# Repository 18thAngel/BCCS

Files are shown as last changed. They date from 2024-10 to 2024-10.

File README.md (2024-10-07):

# BCCS - Brick compatible color shelf

- [BCCS - Brick compatible color shelf](#bccs---brick-compatible-color-shelf)
  - [What is this project about?](#what-is-this-project-about)
  - [How did this project come about?](#how-did-this-project-come-about)
  - [What about the angle bricks?](#what-about-the-angle-bricks)
  - [How to use](#how-to-use)
    - [Pre requirements / Used Software](#pre-requirements--used-software)
    - [Definitions](#definitions)
    - [General](#general)
      - [Customizer - General Settings - Section](#customizer---general-settings---section)
        - [Num Of Fragments](#num-of-fragments)
          - [Example for preview](#example-for-preview)
          - [Example for rendered version](#example-for-rendered-version)
        - [Even number of BrickUnits](#even-number-of-brickunits)
        - [Show Debug outputs and object](#show-debug-outputs-and-object)
    - [Color Holder](#color-holder)
      - [Customizer - Bottle Settings - Section](#customizer---bottle-settings---section)
        - [Clearance](#clearance)
        - [Bottle Type / UserDefined Bottle Diameter](#bottle-type--userdefined-bottle-diameter)
        - [Wall](#wall)
      - [Customizer - Column Settings - Section](#customizer---column-settings---section)
        - [Num of Columns](#num-of-columns)
        - [Space Between Columns](#space-between-columns)
    - [AngleBrick](#anglebrick)
      - [General](#general-1)
  - [Known Issues](#known-issues)
    - [Bricks are very tight](#bricks-are-very-tight)

## What is this project about?

This project allows the creation and printing of compatible holders for building blocks (like LEGO), making it easier to organize and store things like airbrush or tattoo colors. However, during the project, it actually split into two exciting sub-projects:

    The Bottle Holder
    The Angle Brick

## How did this project come about?

My wife, a passionate tattoo artist, asked if I could print her a tiered shelf for her tattoo colors. After discussing the idea, we identified three key requirements that most existing solutions didn’t quite meet:

    Scalability:S
    The collection of colors keeps growing. It would be great if the shelf could expand easily without having to print everything from scratch.

    Adjustable sizes & modularity:
    Different manufacturers have different bottle sizes. A flexible system that can handle various sizes would be ideal. Additionally, when you have more bottles of a particular size, it would be great to use the space more efficiently. This is where a modular system comes in handy.

    Quick to print:
    Let's be honest—many existing solutions take forever to print due to the time needed for the shelf or the underlying structure. But why not use something we already have lying around in abundance, or can get cheaply from third-party suppliers? In this solution, only the actual holders are printed, while the rest is built with building blocks.

## What about the angle bricks?

We’ve all been there: after printing the first few parts, you think, “Hey, this would be even cooler if...”. In this case, the idea was to have angled shelves. Instead of printing new shelves with slanted bases (which I actually tested once), I thought, why not use the formulas I already had for the base calculations to print a brick that serves as an adapter? And voilà, the angle brick was born!

## How to use
### Pre requirements / Used Software
If you want to create a holder based on your own requirements, you'll need the software:
- OpenSCAD (https://openscad.org)

### Definitions
| Term | Explanation |
|---|---|
|`[BrickUnit]`| Size of a single step that can be used for the <br/> `[Width]` or `[Depth]` of a brick. |
| `[BrickLayer]`, `[Layer]`| Size of a single step that can be used for the <br/> `[Height]` dimension of a brick.<br/> (3-layers equal a "normal" brick height )|

### General
All changes should be made within the `Customizer` from OpenSCAD.
Both projects have a `General Settings - Section` with the following parameters.
Whenever something is related to size units. Those are in millimeter [mm] if nothing else is mentioned.

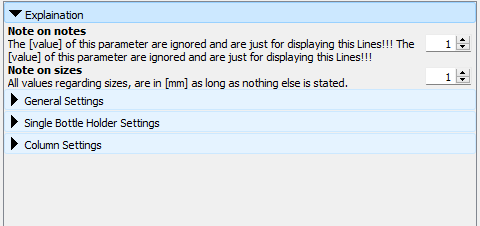
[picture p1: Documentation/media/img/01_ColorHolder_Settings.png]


#### Customizer - General Settings - Section
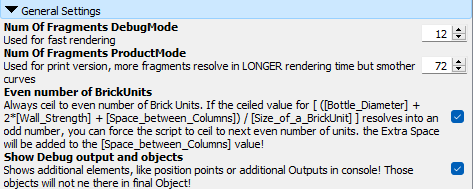
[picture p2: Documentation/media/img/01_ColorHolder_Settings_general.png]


##### Num Of Fragments
As Preview rendering is done in no time at all, it is not that accurate. Therefor any Round surface will be rendered with a limited amount of Fragments. Increasing one of that parameters, will lead to a smoother surface.

###### Example for preview
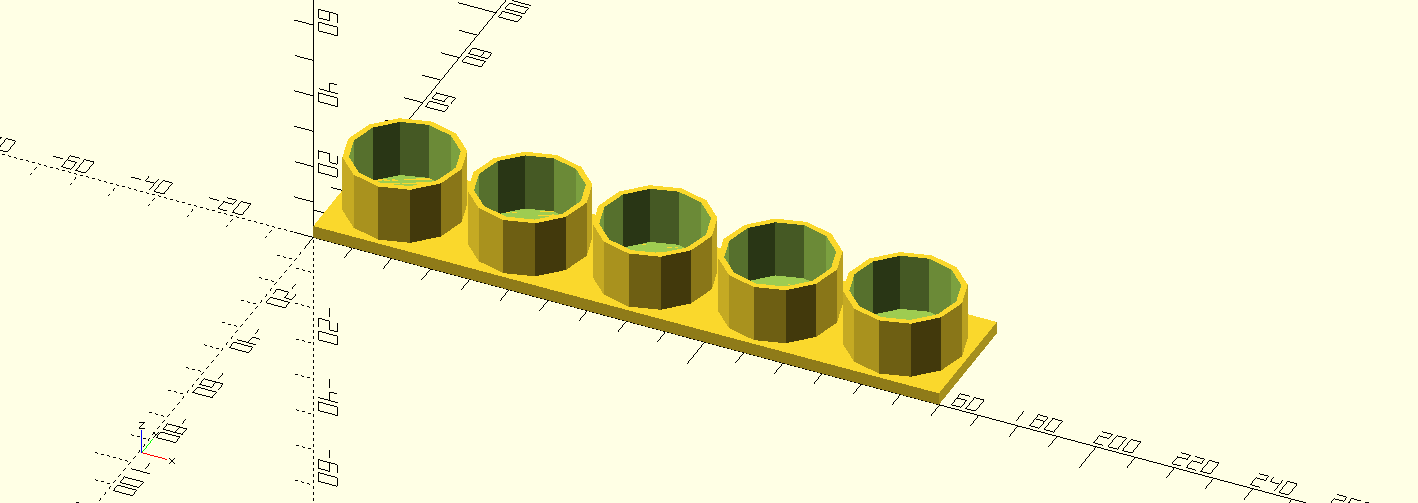
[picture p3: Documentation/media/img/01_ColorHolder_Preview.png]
Example for preview


###### Example for rendered version
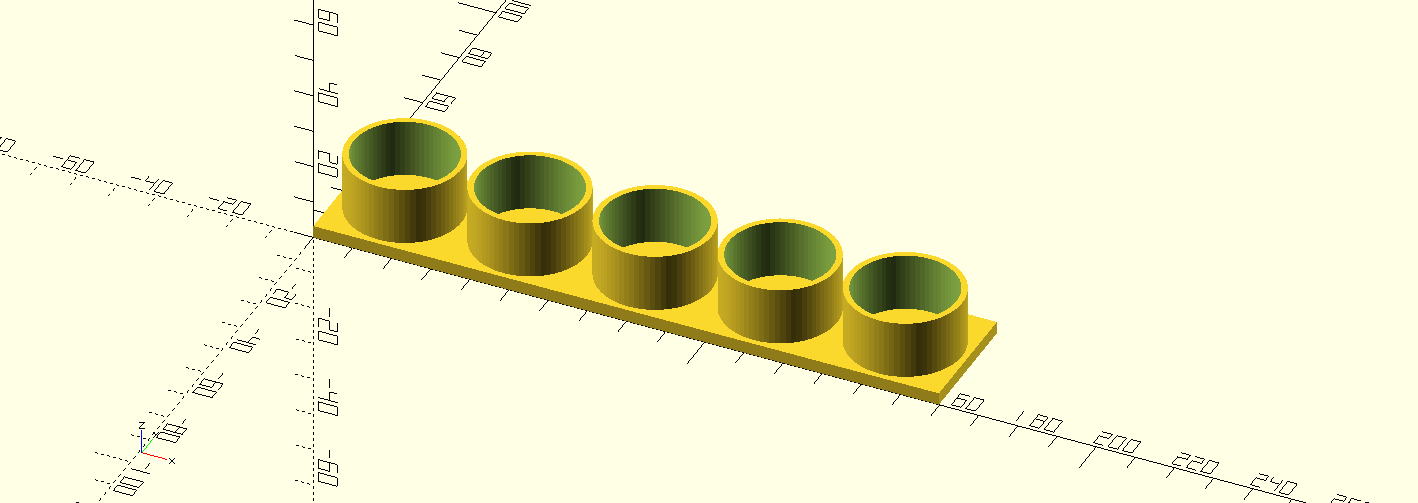
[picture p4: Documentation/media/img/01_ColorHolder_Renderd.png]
Example for rendered version


##### Even number of BrickUnits
To ensure the compatibility to the leading brick systems, the script will always ceil towards whole `[brickUnits]`.

If this option is ticked, it will not just ceil to the next whole `[brickUnit]`, but also to the next __EVEN__ `[brickUnit]`. This can for example be useful to match sizes of baseplates.

##### Show Debug outputs and object
If this option is ticked, additional information are echoed towards console or additional objects might appear on preview. This will be removed while rendering for stl - Export.

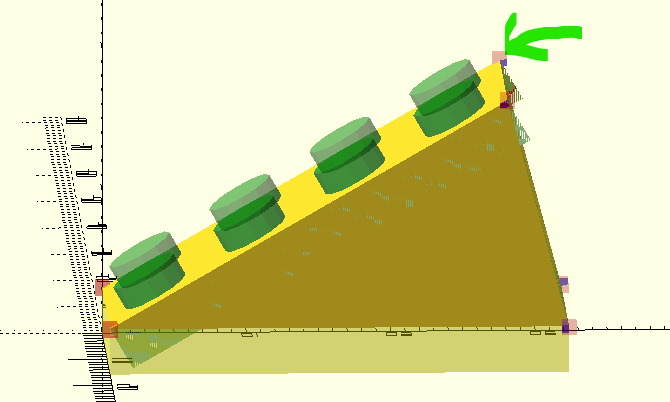
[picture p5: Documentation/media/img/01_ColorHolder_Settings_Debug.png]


### Color Holder
#### Customizer - Bottle Settings - Section
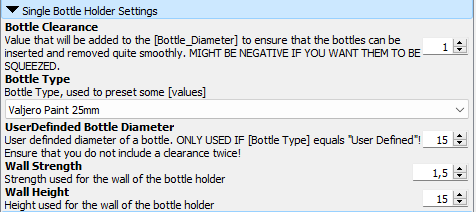
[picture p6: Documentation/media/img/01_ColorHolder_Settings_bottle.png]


##### Clearance
The `[value]` of this parameter will be added to `[bottle diameter]`. To ensure that bottles can be slide in and out easily. 

##### Bottle Type / UserDefined Bottle Diameter
A set of predefined `[bottle diameters]` that are needed frequently.
If the value `User Defined` is selected, the `[UserDefined_Bottle_Diameter]` - value will be used.

##### Wall
The parameters `[Strength]` and `[Height]` define exactly what they are named. 
How thick / high the Wall of the bottleHolder will be.

#### Customizer - Column Settings - Section


##### Num of Columns
Exactly what it sounds like

##### Space Between Columns
This value is more or less the `[min space between holders]`.
After calculating the needed `[brickUnits]` for the holder, the script will spread the holders even over the available space. But sometimes it can save one or two `[brickUnits]` if holder walls, that would normally be touching, would be merged. this can be done by setting this value to a negative value.

__NOTE / TO DO:__ this value must not be set to a value lower than `-[WallStrength]`!<br/>
It is planed to implement a check on that in future versions!

### AngleBrick
#### General
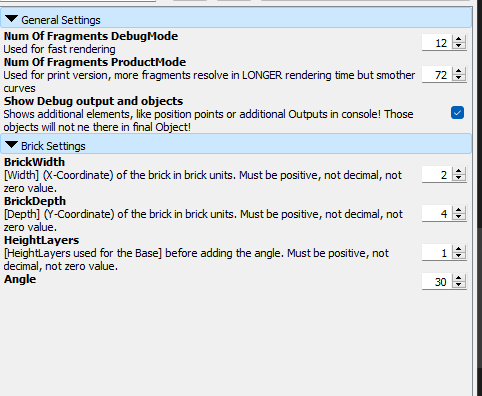
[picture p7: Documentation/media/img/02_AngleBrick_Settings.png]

 Settings for the AngleBrick are straight forward and do not need many explanation.

__Only important info__ is, that the `[Angle]` - value may not be lower than 0°or higher than 90°

## Known Issues
### Bricks are very tight
Reason for that is that i used real dimensions but only have a 0.4 Nozzle. Most likely i will add a little more clearance.
After placing it on a brick with a reasonable amount of force on a "`non printed one`" it will snap in on others as expected

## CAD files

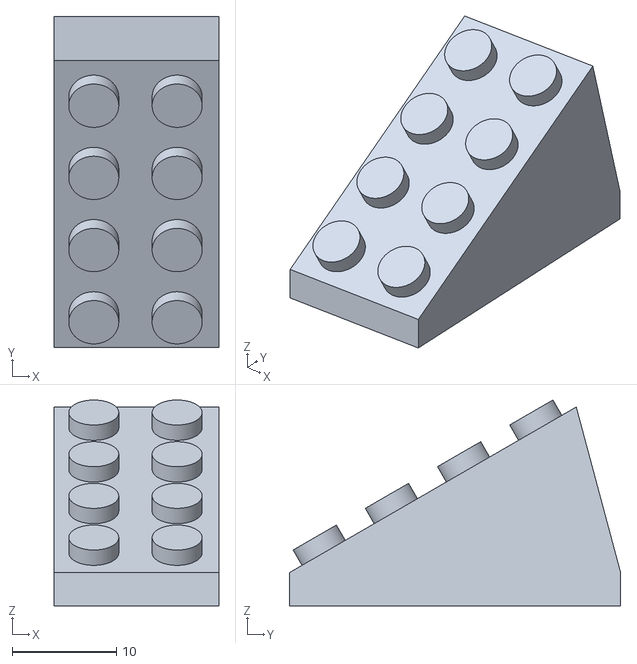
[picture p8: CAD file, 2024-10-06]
Precreated_stls/AngleBrick-2x4_Units-30_Degrees-1_Layer.stl
15.8 x 31.8 x 19.8

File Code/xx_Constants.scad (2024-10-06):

///////////////////////////////////////////////////////////////
// Part of the "Brick compatible color shelf" (BCCS) project //
// File: xx_Constants.scad                                   //
//                                                           //
// By: Alexander Szymanski / 18thAngel                       //
///////////////////////////////////////////////////////////////

// This file generates all important values that are needed to be compatible with most
// modual brick systems.
// The core values have been take from Wikipedia article as of 2024-10-05:
// - https://en.wikipedia.org/wiki/Lego#Design
// - https://en.wikipedia.org/wiki/Lego#/media/File:Lego_dimensions.svg
// some might have been slightly modified to match printers offset


/*[Hidden]*/
///////////////////////
///////////////////////
//// Brick Related ////
///////////////////////
///////////////////////

// as found in Wiki
SmallHeight_of_a_Brick = 3.2; 

// as found in Wiki
Height_of_a_BrickHead = 1.7;

// as found in Wiki
Diameter_of_a_BrickHead = 4.8;

// as found in Wiki
Clearance_of_a_Brick = 0.2;

// messured from a brick on my desk
InnerWallStrength_of_a_Brick = 0.85;

// assumed
TopWallStrength_of_a_Brick = 1.2;

//TODO: make it a param in customizer!
// This is just, as my printer is not that precise
OutterWallStrength_additional_clearance= 0.1;

//////////////////////////
// Precalculated Values //
//////////////////////////

// A brick can be cutted in three parts / layers 
// and is allowed to be any non decimal multiplication of that layer height
// Original the normal brick is SmallHeight_of_a_Brick * 3;
Height_of_a_Brick = SmallHeight_of_a_Brick * 3;

// Values, that are related to width and depth of a brick are fixed to brick units
// 1 brick unit is calculated by SmallHeight_of_a_Brick * 2.5;
// Values [Width] and [Depth] of a brick must match a non decimal multiplication of a brick unit
Size_of_a_BrickUnit = SmallHeight_of_a_Brick * 2.5;

// Value that is used for any outter walls regarding [Width] and [Depth], most likely it could also be used for height
// Calculation:
// ([Size of a single brick unit] - [clearance of a brick] - [diameter of a brick head]) / 2
OutterWallStrength_of_a_Brick = ((Size_of_a_BrickUnit - Clearance_of_a_Brick - Diameter_of_a_BrickHead) / 2)-OutterWallStrength_additional_clearance;

// For better fitting, the total [Width] and [Depth] of a brick will be lowered by 0.2 mm
// that helps to stack those bricks, or tear them apart
Width_of_a_Brick = Size_of_a_BrickUnit - Clearance_of_a_Brick;

// Simple Diameter => Radius calc
Radius_of_a_BrickHead = Diameter_of_a_BrickHead / 2;

// According to the Specs, it should be +0.1,
// as it doubles up when we convert it back to a radius
// but in this case it did not worked with my printer! 
// this value will be substracted (difference) from [OutterRadius_of_a_BrickHole]
InnerRadius_of_a_BrickHole = Radius_of_a_BrickHead + 0.2;

// Size of a brickhead increased the strength of inner walls
OutterRadius_of_a_BrickHole = Radius_of_a_BrickHead + InnerWallStrength_of_a_Brick;

// Thickness used for the [Thickness:Z] of the tile base. For Historical Reasons!
Thickness_of_tile_base = SmallHeight_of_a_Brick;

////////////////////////
////////////////////////
//// Bottle Related ////
////////////////////////
////////////////////////

////////////////////
// Bottle_presets //
////////////////////
_v_diameter = 25;
_gb26_diameter = 26;
_gb30_diameter = 30;
_gb32_diameter = 32;
_gb35_diameter = 35;
_gb37_diameter = 37;


// Not a const, i know! 
// returns the Diameter for the given string
function GetBottleDiameter(bottleType,userDefindedBottleDiameter) = 
  bottleType=="v" ? _v_diameter
: bottleType=="gb26" ? _gb26_diameter
: bottleType=="gb30" ? _gb30_diameter
: bottleType=="gb32" ? _gb32_diameter
: bottleType=="gb35" ? _gb35_diameter
: bottleType=="gb37" ? _gb37_diameter
:userDefindedBottleDiameter;

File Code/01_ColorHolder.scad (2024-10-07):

///////////////////////////////////////////////////////////////
// Part of the "Brick compatible color shelf" (BCCS) project //
// File: 01_ColorHolder.scad                                 //
//                                                           //
// By: Alexander Szymanski / 18thAngel                       //
///////////////////////////////////////////////////////////////

include <xx_Constants.scad>
include <xx_SharedStuff.scad>

/*[Explaination]*/
// The [value] of this parameter are ignored and are just for displaying this Lines!!! The [value] of this parameter are ignored and are just for displaying this Lines!!!
Note_on_notes = 1;
// All values regarding sizes, are in [mm] as long as nothing else is stated.
Note_on_sizes = 1;

/*[General Settings]*/
// Used for fast rendering
Num_Of_Fragments_DebugMode = 12;

// Used for print version, more fragments resolve in LONGER rendering time but smother curves
Num_Of_Fragments_ProductMode = 72;

// Always ceil to even number of Brick Units. If the ceiled value for [ ([Bottle_Diameter] + 2*[Wall_Strength] + [Space_between_Columns]) / [Size_of_a_BrickUnit] ] resolves into an odd number, you can force the script to ceil to next even number of units. the Extra Space will be added to the [Space_between_Columns] value!
Even_number_of_BrickUnits = true;

// Shows additional elements, like position points or additional Outputs in console! Those objects will not ne there in final Object!
Show_Debug_output_and_objects = true;

/*[Single Bottle Holder Settings]*/
// Value that will be added to the [Bottle_Diameter] to ensure that the bottles can be inserted and removed quite smoothly. MIGHT BE NEGATIVE IF YOU WANT THEM TO BE SQUEEZED.
Bottle_Clearance = 1;

// Bottle Type, used to preset some [values]
Bottle_Type =  "v"; // [ud:User Defined, v:Valjero Paint(25mm), gb26:Generic 26mm Bottle, gb30:Generic 30mm Bottle, gb32:Generic 32mm Bottle, gb35:Generic 35mm Bottle, gb37:Generic 37mm Bottle]

// User definded diameter of a bottle. ONLY USED IF [Bottle Type] equals "User Defined"! Ensure that you do not include a clearance twice!
UserDefinded_Bottle_Diameter = 15;

// determied by previous selections - not visible in Customizer!
Bottle_Diameter = GetBottleDiameter(Bottle_Type, UserDefinded_Bottle_Diameter) + Bottle_Clearance;

// Strength used for the wall of the bottle holder
Wall_Strength = 1.5;

// Height used for the wall of the bottle holder
Wall_Height = 15;

/*[Column Settings]*/
// Number of [bottles] per [row]
Num_of_Columns = 5;
// Space between [bottles] in a [row]. May be negative but only by [real space between bottle holders] + 1 * [Wall Strength]
Space_between_Columns = 1;


//////////////////////////////
// !!! No changes below !!! //
//////////////////////////////
include <xx_lateCalculatedValues.scad>
///////////////////////
// Value Calculation //
///////////////////////

// General
$fn = $preview ? Num_Of_Fragments_DebugMode : Num_Of_Fragments_ProductMode;

// Tile Related
// Size that is used for [Length:X] and [Depth:Y] of the tile
Size_of_Tile = Bottle_Diameter + 2 * Wall_Strength;

minSpaceBetweenColumns = (Bottle_Diameter + Wall_Strength) - Size_of_Tile;

tileDepth =
    CalcRealSize(Size_of_Tile, Size_of_a_BrickUnit, Even_number_of_BrickUnits);
tileDepthOverhead = tileDepth - Size_of_Tile;

///////////////////////
// Value Calculation //
///////////////////////

// Bottle related
BottleHolder_OutterRadius = Bottle_Diameter / 2 + Wall_Strength;
BottleHolder_InnerRadius = Bottle_Diameter / 2;

// Tile Related
BaseSizeWidth_tmp = (BottleHolder_OutterRadius * 2 * Num_of_Columns) +
                    ((Num_of_Columns)*Space_between_Columns);

BaseSizeWidth = CalcRealSize(BaseSizeWidth_tmp, Size_of_a_BrickUnit,
                             Even_number_of_BrickUnits);

BaseSizeWidth_overhead = BaseSizeWidth - BaseSizeWidth_tmp;

CalcedSpaceBetween =
    Space_between_Columns + (BaseSizeWidth_overhead / NotZero(Num_of_Columns));

///////////////////////////
unitsWidth = (BaseSizeWidth + Clearance_of_a_Brick) / Size_of_a_BrickUnit;
unitsDepth = (tileDepth+Clearance_of_a_Brick) / Size_of_a_BrickUnit;
///////////////////////////

if (DebugMode) {
  echo("");
  echo("----------------------------");
  echo("Important calculation results:");
  echo("");

  echo(str("The real base width for ", BaseSizeWidth_tmp,
           "mm has been calced to: ", BaseSizeWidth, "mm"));
  echo(str("CalcedSpaceBetween has been calced to ", CalcedSpaceBetween, "mm"));
  echo("");
  echo("----------------------------");
  echo("");

  echo("");
  echo("----------------------------");
  echo("Settings for a bottle:");
  echo("");
  echo(str("[Bottle Diameter] for [Bottle_Type]: ", Bottle_Type,
           " have been set to: ", Bottle_Diameter,
           "mm, including: ", Bottle_Clearance,
           "mm [Bottle Clearance], based on user preferences"));
  echo("");
  echo("----------------------------");
  echo("");

  echo("");
  echo("----------------------------");
  echo("Messures of a brick:");
  echo("");

  echo(str("Small height of a brick: ", SmallHeight_of_a_Brick, "mm (given)"));
  echo(str("Height of a brick head: ", Height_of_a_BrickHead, "mm (given)"));
  echo(
      str("Diameter of a brick head: ", Diameter_of_a_BrickHead, "mm (given)"));
  echo(str("Height of a brick: ", Height_of_a_Brick, "mm (calc)"));
  echo(str("Size of a brick unit: ", Size_of_a_BrickUnit, "mm (calc)"));
  echo(str("Width of a brick:  ", Width_of_a_Brick, "mm (calc)"));
  echo(str("Radius_of_a_BrickHead:  ", Radius_of_a_BrickHead, "mm (calc)"));
  echo(str("InnerRadius of a BrickHole:  ", InnerRadius_of_a_BrickHole,
           "mm (calc)"));
  echo(str("OutterRadius of a BrickHole:  ", OutterRadius_of_a_BrickHole,
           "mm (calc)"));
  echo("");

  echo("Messures the Holder:");
  echo("");
  echo(str("The real tile depth for ", Size_of_Tile,
           "mm has been calced to: ", tileDepth, "mm"));
  echo(str("The real base width for ", BaseSizeWidth_tmp,
           "mm has been calced to: ", BaseSizeWidth, "mm"));
  echo(str("Tile depth:  ", tileDepth, "mm (calc)"));
  echo(str("Tile width:  ", BaseSizeWidth, "mm (calc)"));
  echo(str("Tile depth:  ", unitsDepth, "units (calc)"));
  echo(str("Tile width:  ", unitsWidth, "units (calc)"));
  echo("");
  echo("----------------------------");
  echo("");

  echo(str("The real tile depth for ", Size_of_Tile,
           "mm has been calced to: ", tileDepth, "mm"));
}
// generates a single Holder
module BottleHolder() {
  translate([ 0, BottleHolder_OutterRadius + tileDepthOverhead / 2, 0 ]) {
    difference() {
      cylinder(Wall_Height, BottleHolder_OutterRadius,
               BottleHolder_OutterRadius);
      cylinder(Wall_Height + 0.1, BottleHolder_InnerRadius,
               BottleHolder_InnerRadius);
    }
  }
}
// generates a single Holder
module BottleHolders() {
  for (holder = [0:Num_of_Columns - 1]) {
    translate([
      (holder * (BottleHolder_OutterRadius * 2 + CalcedSpaceBetween)) +
          BottleHolder_OutterRadius,
      0,
      Thickness_of_tile_base
    ]) BottleHolder();
  }
}

// Generates a Single Row, in original version there were a multiple rows option!
module SolidHolder() {
  Base(unitsWidth,unitsDepth);
  translate([ CalcedSpaceBetween / 2, 0, 0 ]) BottleHolders();
}



/////////////////

/////////////
// Program //
/////////////

// in original version there were a multiple rows option!
SolidHolder();  

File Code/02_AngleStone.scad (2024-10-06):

///////////////////////////////////////////////////////////////
// Part of the "Brick compatible color shelf" (BCCS) project //
// File: 02_AngleStone.scad                                  //
//                                                           //
// By: Alexander Szymanski / 18thAngel                       //
///////////////////////////////////////////////////////////////

include <xx_Constants.scad>
include <xx_SharedStuff.scad>

/*[General Settings]*/
// Used for fast rendering
Num_Of_Fragments_DebugMode = 12;

// Used for print version, more fragments resolve in LONGER rendering time but smother curves
Num_Of_Fragments_ProductMode = 72;

// Shows additional elements, like position points or additional Outputs in console! Those objects will not ne there in final Object!
Show_Debug_output_and_objects = true;
/*[Brick Settings]*/
// [Width] (X-Coordinate) of the brick in brick units. Must be positive, not decimal, not zero value.
BrickWidth = 2;
// [Depth] (Y-Coordinate) of the brick in brick units. Must be positive, not decimal, not zero value.
BrickDepth = 4;
// [HeightLayers used for the Base] before adding the angle. Must be positive, not decimal, not zero value.
HeightLayers = 1;

Angle = 30;

//////////////////////////////
// !!! No changes below !!! //
//////////////////////////////
include <xx_lateCalculatedValues.scad>
///////////////////////
// Value Calculation //
///////////////////////

// General
$fn = $preview ? Num_Of_Fragments_DebugMode : Num_Of_Fragments_ProductMode;


_origin_x = GetSizeByBrickUnits(BrickWidth, Size_of_a_BrickUnit);
_origin_y = GetSizeByBrickUnits(BrickDepth, Size_of_a_BrickUnit);
_origin_z = SmallHeight_of_a_Brick * HeightLayers;


correctedPosition = CalcTanslationAfterRotation([0,0,_origin_z], Angle);
topLocation = CalcPositionAfterRotation([0,_origin_y,_origin_z], Angle) + correctedPosition ;
bottomLocation = CalcPositionAfterRotation([0,0,0], Angle) + correctedPosition;

// filling the gap
module GapFill() {

    _fillPoints=[
     [  0,  0, _origin_z ],  //0 
     [  _origin_x,  0, _origin_z ],  //1 
     [  _origin_x,  _origin_y, _origin_z ],  //2 
     [  0,  _origin_y, _origin_z ],  //3
     [  0,  topLocation[1], topLocation[2] ],  //4 
     [  _origin_x,  topLocation[1], topLocation[2] ],  //5 
     ];

    _fillFaces= [
        [0,1,2,3], // bottom
        [4,5,1,0], //Front
        [5,4,3,2],  // back
        [0,3,4],  // Left
        [1,2,5],  // right
    ];
hull() {
   polyhedron( _fillPoints, _fillFaces );
}
    if(DebugMode)
        for(point = _fillPoints)
            color("red",0.3) 
              translate(point)     
                cube(size = 1, center=true);
}

module buildTopPart()
{
    difference() 
    {
        translate(correctedPosition)
            rotate([Angle,0,0])
                color("green",0.5) 
                    Base(BrickWidth,BrickDepth, HeightLayers,true,false);
    
        //TODO; lazy way of cutting may be fixed 
        
        translate(correctedPosition+[0,0.1,-0.1])
            rotate([Angle,0,0])
                color("red",0.5) 
                    Base(BrickWidth,BrickDepth, HeightLayers,false,false);
        translate(correctedPosition+[0,-0.1,-0.1])
            rotate([Angle,0,0])
                color("red",0.5) 
                    Base(BrickWidth,BrickDepth, HeightLayers,false,false);
    }       
}

module buildTheBasic()
{
    buildTopPart();
    color("yellow",0.5) 
    Base(BrickWidth,BrickDepth, HeightLayers,false);
    
 
}

module Brick() {
  buildTheBasic();
  GapFill();
        
}

module FinalBrick() {
  difference() {
    Brick();
  BuildTheCutter();
  
    
    }
}

module BuildTheCutter() {
    _cutterPoints=[         
        [  0,  _origin_y, _origin_z ],  //1
        [  _origin_x,  _origin_y, _origin_z ],  //0 
        [  _origin_x,  _origin_y, _origin_z ]+ correctedPosition,  //3
        [  0,  _origin_y, _origin_z ] + correctedPosition,  //2
        [  0,  topLocation[1], topLocation[2] ],  //4 
        [  _origin_x,  topLocation[1], topLocation[2] ],  //5 
        [  _origin_x,  topLocation[1], topLocation[2] ]+ correctedPosition,  //6
        [  0,  topLocation[1], topLocation[2] ]+ correctedPosition,  //7
    ];

    _cutterFaces = [
  [0,1,2,3],  // bottom
  [4,5,1,0],  // front
  [7,6,5,4],  // top
  [5,6,2,1],  // right
  [6,7,3,2],  // back
  [7,4,0,3]]; // left
    
    if(DebugMode)
        for(point = _cutterPoints)
            color("blue",0.5) 
              translate(point)     
                cube(size = 1, center=true);

    polyhedron( _cutterPoints, _cutterFaces );

}

 //Brick();

//   BuildTheCutter();
   //GapFill();
   FinalBrick();
   //buildTopPart();

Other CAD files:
Code/xx_lateCalculatedValues.scad
Code/xx_SharedStuff.scad

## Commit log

2024-10-05 Added Presets for some Bottles
    [01_ColorHolder.scad, xx_Constants.scad, xx_SharedStuff.scad]
2024-10-05 Many Explaination, little cleanup
    [01_ColorHolder.scad]
2024-10-05 made Base generation more generic
    [01_ColorHolder.scad, 02_AngleStone.scad, xx_Constants.scad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]
2024-10-05 Full working stone generation
    [02_AngleStone.scad, xx_SharedStuff.scad]
2024-10-05 Es lebt!!!
    [02_AngleStone.scad, xx_SharedStuff.scad]
2024-10-05 Schluss für heute
    [02_AngleStone.scad, xx_SharedStuff.scad]
2024-10-05 ES LEBTTTTT!!!
    [02_AngleStone.scad, 2x4_15AngleBrick.stl, xx_SharedStuff.scad]
2024-10-06 Found issue,!
    Too tight!
    Fill is filling wrong area
    [1x4_10AngleBrick.stl, 1x4_15AngleBrick.stl, 1x4_30AngleBrick.stl]
2024-10-06 Pre Unit Test
    [01_ColorHolder.scad, 02_AngleStone.scad, xx_Constants.scad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]
2024-10-06 Fixed Quick n dirty
    [02_AngleStone.scad, xx_SharedStuff.scad]
2024-10-06 Next test print
    [02_AngleStone.scad, 1x2_30AngleBrick.stl, 2x2_30AngleBrick.stl]
2024-10-07 Spell correction / advanced Docu
    [01_ColorHolder.scad, 1x2_30AngleBrick.stl, 1x4_10AngleBrick.stl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]
